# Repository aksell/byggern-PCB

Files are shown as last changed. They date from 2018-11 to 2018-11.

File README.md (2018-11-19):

# byggern-PCB
Board that replaces node 1 in Embedded and Industrial Computer Systems Design project at NTNU. 

The two layer board is designed using [kicad](http://kicad-pcb.org/help/getting-started/) 

## Schematic
Download pdf version [here](./pictures/schematic.pdf)
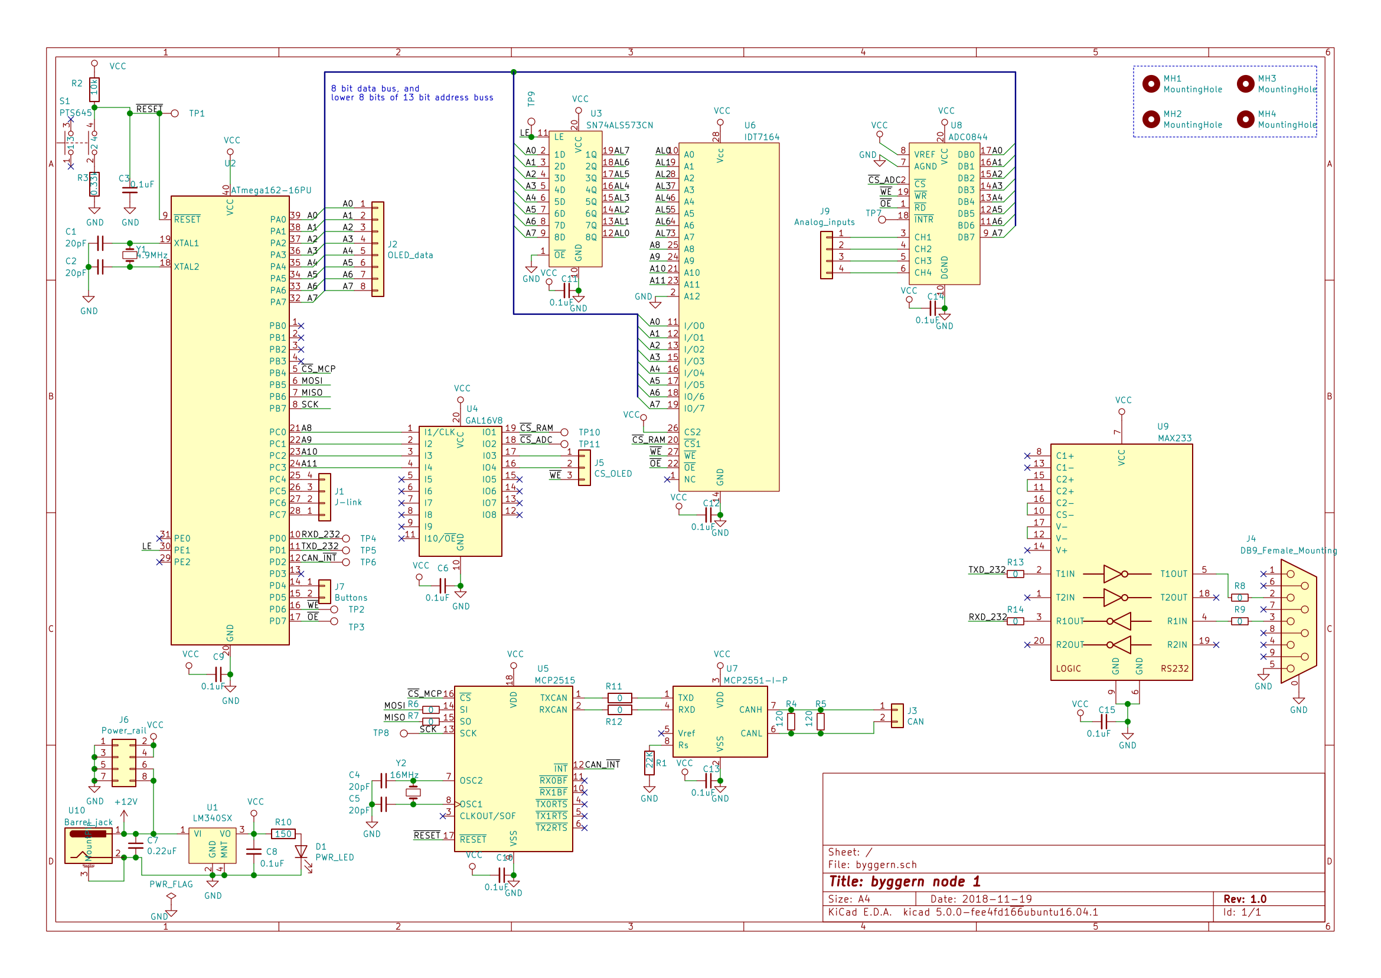
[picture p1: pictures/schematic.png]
schematic


## Rendering of board
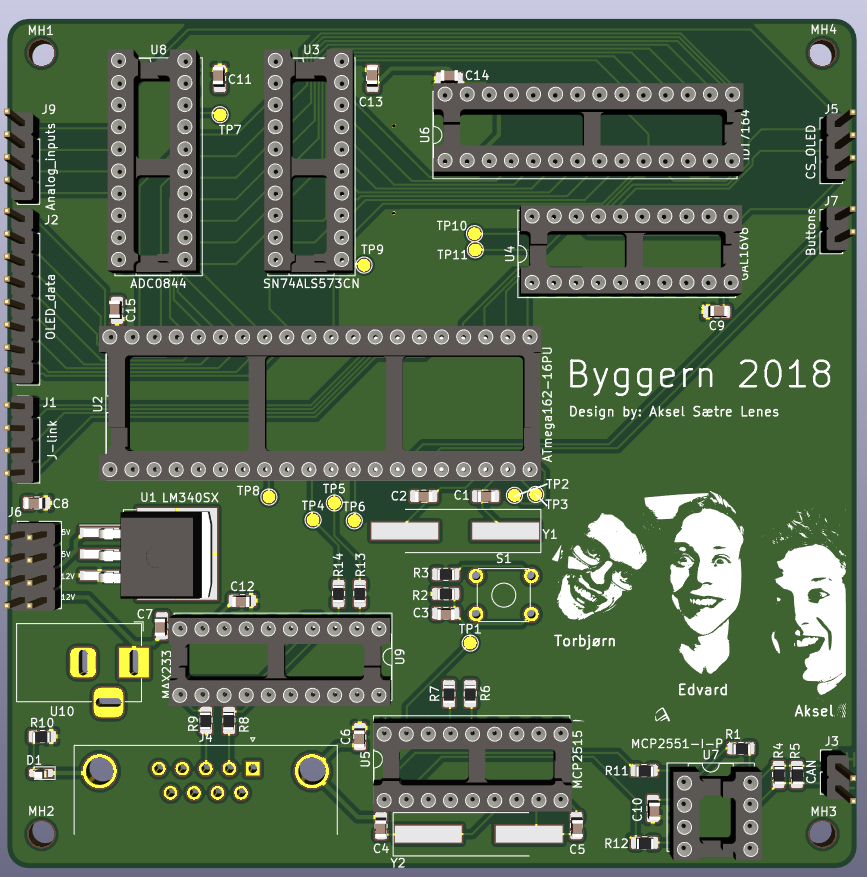
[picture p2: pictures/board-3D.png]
board-3D


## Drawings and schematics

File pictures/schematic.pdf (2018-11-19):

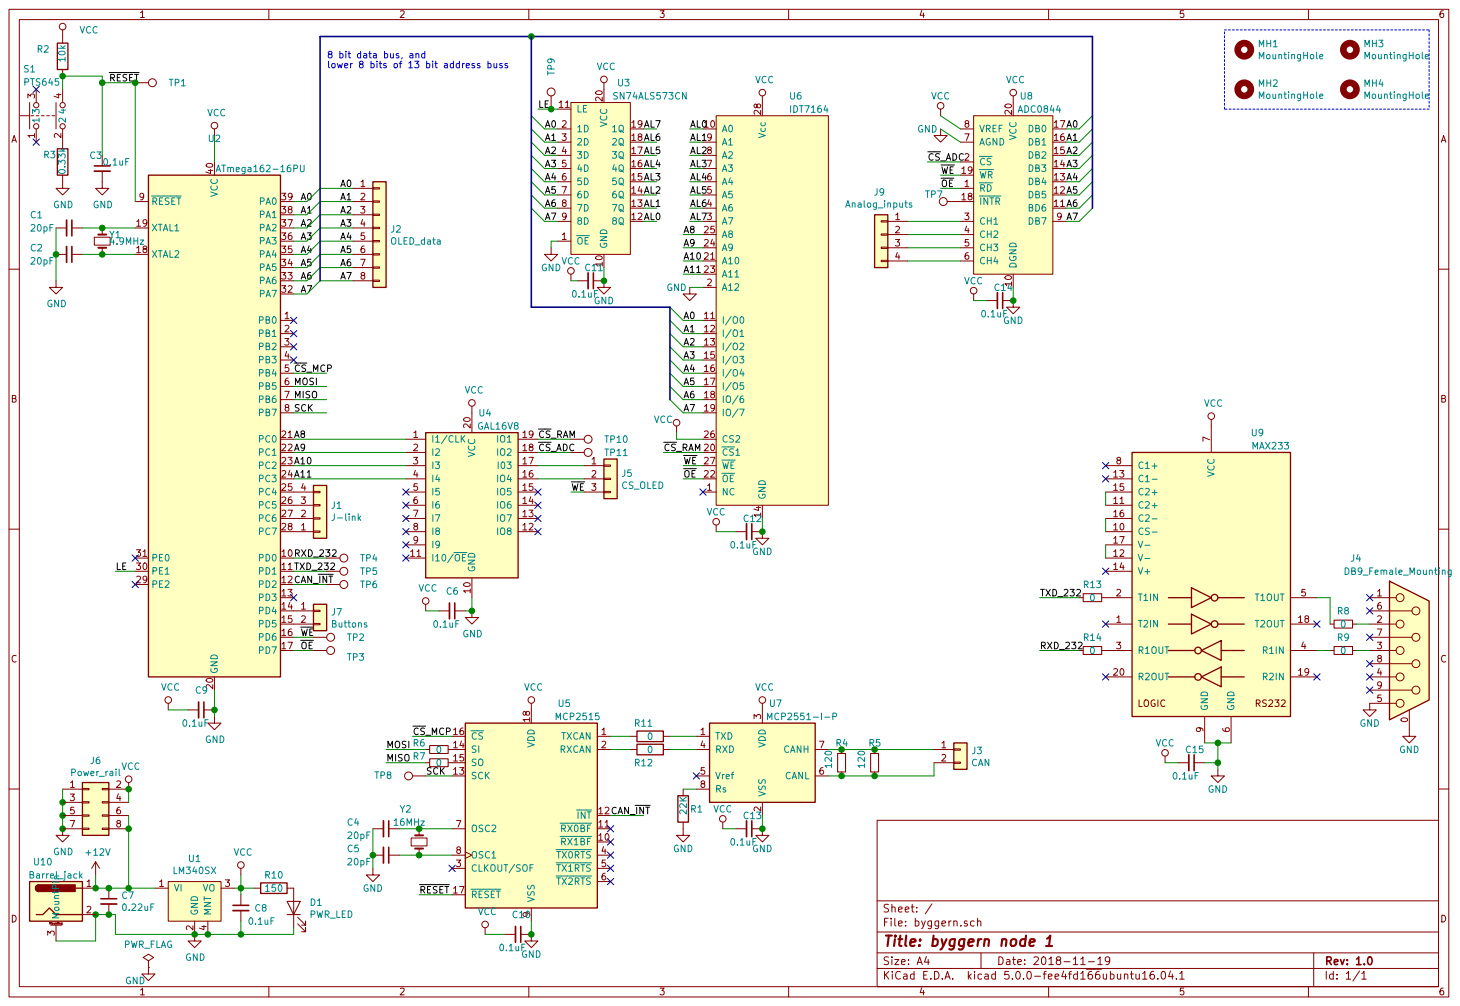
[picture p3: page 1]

8 bit data bus, and
lower 8 bits of 13 bit address buss

I4 4 | 2
I5 5 I6 6 I7 7 I8 8 I9 9 I10/OE 11 | 3

3 RXD 4 Vref 5 CANL 6 CANH 7 Rs 8 U7MCP2551-I-P GND

File: byggern.sch Sheet: /
Id: 1/1 Title: byggern node 1

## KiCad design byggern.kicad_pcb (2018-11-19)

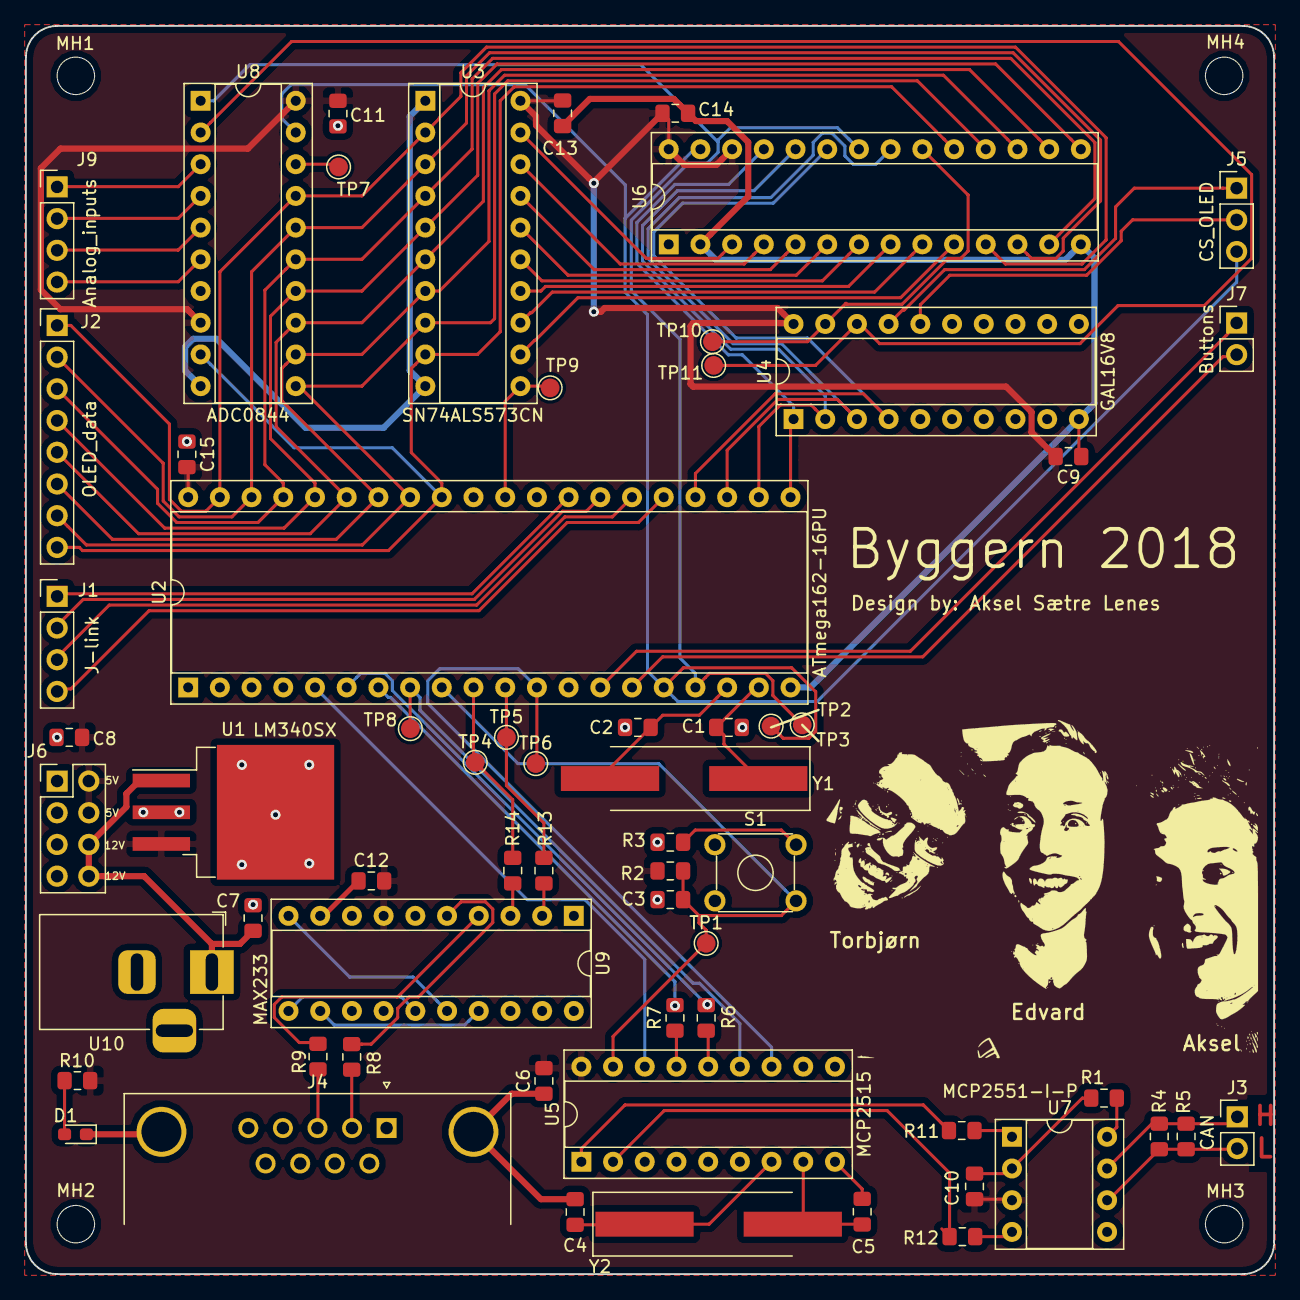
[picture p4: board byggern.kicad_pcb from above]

Board: 2 copper layers, 100.0 x 100.0 mm, 66 parts (0 on the bottom side), 73 nets.

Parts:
C1, C2, C4, C5: 20pF; C_0805_2012Metric_Pad1.15x1.40mm_HandSolder
C3, C6, C8, C9, C10, C11, C12, C13, C14, C15: 0.1uF; C_0805_2012Metric_Pad1.15x1.40mm_HandSolder
C7: 0.22uF; C_0805_2012Metric_Pad1.15x1.40mm_HandSolder
D1: PWR_LED; LED_0603_1608Metric_Pad1.05x0.95mm_HandSolder
J1: J-link; PinHeader_1x04_P2.54mm_Vertical
J2: OLED_data; PinHeader_1x08_P2.54mm_Vertical
J3: CAN; PinHeader_1x02_P2.54mm_Vertical
J4: DB9_Female_Mounting; DSUB-9_Female_Horizontal_P2.77x2.84mm_EdgePinOffset4.94mm_H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
J5: CS_OLED; PinHeader_1x03_P2.54mm_Vertical
J6: Power_rail; PinHeader_2x04_P2.54mm_Vertical
J7: Buttons; PinHeader_1x02_P2.54mm_Vertical
J9: Analog_inputs; PinHeader_1x04_P2.54mm_Vertical
MH1, MH2, MH3, MH4: MountingHole; MountingHole_3mm
R1: 22K; R_0805_2012Metric_Pad1.15x1.40mm_HandSolder
R2: 10k; R_0805_2012Metric_Pad1.15x1.40mm_HandSolder
R3: 0.33k; R_0805_2012Metric_Pad1.15x1.40mm_HandSolder
R4, R5: 120; R_0805_2012Metric_Pad1.15x1.40mm_HandSolder
R6, R7, R8, R9, R11, R12, R13, R14: 0; R_0805_2012Metric_Pad1.15x1.40mm_HandSolder
R10: 150; R_0805_2012Metric_Pad1.15x1.40mm_HandSolder
S1: PTS645; SW_TH_Tactile_Omron_B3F-10xx
TP1, TP2, TP3, TP4, TP5, TP6, TP7, TP8, TP9, TP10, TP11: TestPoint_Pad_D1.5mm
U1: LM340SX; TO-263-3_TabPin4
U2: ATmega162-16PU; DIP-40_W15.24mm_Socket
U3: SN74ALS573CN; DIP-20_W7.62mm_Socket
U4: GAL16V8; DIP-20_W7.62mm_Socket
U5: MCP2515; DIP-18_W7.62mm_Socket
U6: IDT7164; DIP-28_W7.62mm_Socket
U7: MCP2551-I-P; DIP-8_W7.62mm_Socket
U8: ADC0844; DIP-20_W7.62mm_Socket
U9: MAX233; DIP-20_W7.62mm_Socket
U10: Barrel_jack; BarrelJack_Horizontal
Y1: 4.9MHz; Crystal_SMD_HC49-SD_HandSoldering
Y2: 16MHz; Crystal_SMD_HC49-SD_HandSoldering

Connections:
+12V: C7.1, J6.6, J6.8, U1.1, U10.1
/A0: J2.1, U2.39, U3.2, U6.11, U8.17
/A1: J2.2, U2.38, U3.3, U6.12, U8.16
/A2: J2.3, U2.37, U3.4, U6.13, U8.15
/A3: J2.4, U2.36, U3.5, U6.15, U8.14
/A4: J2.5, U2.35, U3.6, U6.16, U8.13
/A5: J2.6, U2.34, U3.7, U6.17, U8.12
/A6: J2.7, U2.33, U3.8, U6.18, U8.11
/A7: J2.8, U2.32, U3.9, U6.19, U8.9
/A8: U2.21, U4.1, U6.25
/A9: U2.22, U4.2, U6.24
/A10: U2.23, U4.3, U6.21
/A11: U2.24, U4.4, U6.23
/AL0: U3.12, U6.10
/AL1: U3.13, U6.9
/AL2: U3.14, U6.8
/AL3: U3.15, U6.7
/AL4: U3.16, U6.6
/AL5: U3.17, U6.5
/AL6: U3.18, U6.4
/AL7: U3.19, U6.3
/CAN_~INT: TP6.1, U2.12, U5.12
/LE: TP9.1, U2.30, U3.11
/MISO: R7.2, U2.7
/MOSI: R6.2, U2.6
/RXD_232: R14.2, TP4.1, U2.10
/SCK: TP8.1, U2.8, U5.13
/TXD_232: R13.2, TP5.1, U2.11
/~CS~_ADC: TP11.1, U4.18, U8.2
/~CS~_MCP: U2.5, U5.16
/~CS~_RAM: TP10.1, U4.19, U6.20
/~OE: TP3.1, U2.17, U6.22, U8.1
/~RESET: C3.1, R2.1, S1.4, TP1.1, U2.9, U5.17
/~WE: J5.3, TP2.1, U2.16, U6.27, U8.19
GND: C1.2, C2.2, C3.2, C4.2, C5.2, C6.1, C7.2, C8.2, C9.1, C10.1, C11.1, C12.1, C13.1, C14.1, C15.1, D1.1, J4.0, J4.5, J6.1, J6.3, J6.5, J6.7, R1.2, R3.1, U1.2, U1.4, U2.20, U3.1, U3.10, U4.10, U5.9, U6.2, U6.14, U7.2, U8.7, U8.10, U9.6, U9.9, U10.2, U10.3
unnamed: C1.1, U2.19, Y1.1
unnamed: C2.1, U2.18, Y1.2
unnamed: C4.1, U5.7, Y2.1
unnamed: C5.1, U5.8, Y2.2
unnamed: D1.2, R10.1
unnamed: J1.1, U2.28
unnamed: J1.2, U2.27
unnamed: J1.3, U2.26
unnamed: J1.4, U2.25
unnamed: J3.1, R4.1, R5.1, U7.7
unnamed: J3.2, R4.2, R5.2, U7.6
unnamed: J4.2, R8.1
unnamed: J4.3, R9.1
unnamed: J5.1, U4.17
unnamed: J5.2, U4.16
unnamed: J7.1, U2.14
unnamed: J7.2, U2.15
unnamed: J9.1, U8.3
unnamed: J9.2, U8.4
unnamed: J9.3, U8.5
unnamed: J9.4, U8.6
unnamed: R1.1, U7.8
unnamed: R3.2, S1.2
unnamed: R6.1, U5.14
unnamed: R7.1, U5.15
unnamed: R8.2, U9.5
unnamed: R9.2, U9.4
unnamed: R11.1, U7.1
unnamed: R11.2, U5.1
unnamed: R12.1, U7.4
unnamed: R12.2, U5.2
unnamed: R13.1, U9.2
unnamed: R14.1, U9.3
unnamed: TP7.1, U8.18
unnamed: U9.10, U9.16
unnamed: U9.11, U9.15
unnamed: U9.12, U9.17
VCC: C6.2, C8.1, C9.2, C10.2, C11.2, C12.2, C13.2, C14.2, C15.2, J6.2, J6.4, R2.2, R10.2, U1.3, U2.40, U3.20, U4.20, U5.18, U6.26, U6.28, U7.3, U8.8, U8.20, U9.7

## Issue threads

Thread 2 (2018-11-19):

Change to smd footprinf for reset button

aksell, 2018-11-19:
The thru hole footprint works fine, but he reset button used is a SMD component so the footprint should be changed to SMD pads.

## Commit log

2018-11-19 Add project files
    [byggern.kicad_pcb, byggern.sch]
2018-11-19 Add gerber and drill files
    [byggern-B.Cu.gbr, byggern-B.Mask.gbr, byggern-Edge.Cuts.gbr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]
2018-11-19 Output fabrication files too fabrication_files directory
    [byggern.kicad_pcb]
2018-11-19 Upload schematic and render of board
